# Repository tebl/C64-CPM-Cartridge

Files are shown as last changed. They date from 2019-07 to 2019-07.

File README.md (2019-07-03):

# C64 CP/M Cartridge

**UNTESTED**

Always wanted one of these for the original system, but they're hard to get so I've tried to recreate the cartridge itself for others to enjoy as well. For beginners and those with short memory, CP/M was professional choice of operating system for home computer markets - so if you wanted tax software, word processing and similar exciting tools this was the one you wanted for christmas. The system ran mainly on Z80-based systems while the Commodore 64 had a 6510 in it, so the cartridge was created in order to allow you to use the Z80 processor instead. Note that this is not a secondary processor, the Z80 shares all the main busses with the 6510 so only one of them can be active at a time.

There was no official schematic released for the module, none that I've seen anyway. Ruud Baltissen has taken upon himself the task of documenting the details of the module with a schematic, see his page at http://www.baltissen.org/newhtm/c64_cpm.htm for a lot more information on how the module works. My schematic has been transcribed from the one he made, then a PCB layout was done. Edge connector footprint was borrowed from the [Open16KCartridge](https://github.com/SukkoPera/OpenC64Cart16K) made by SukkoPera.

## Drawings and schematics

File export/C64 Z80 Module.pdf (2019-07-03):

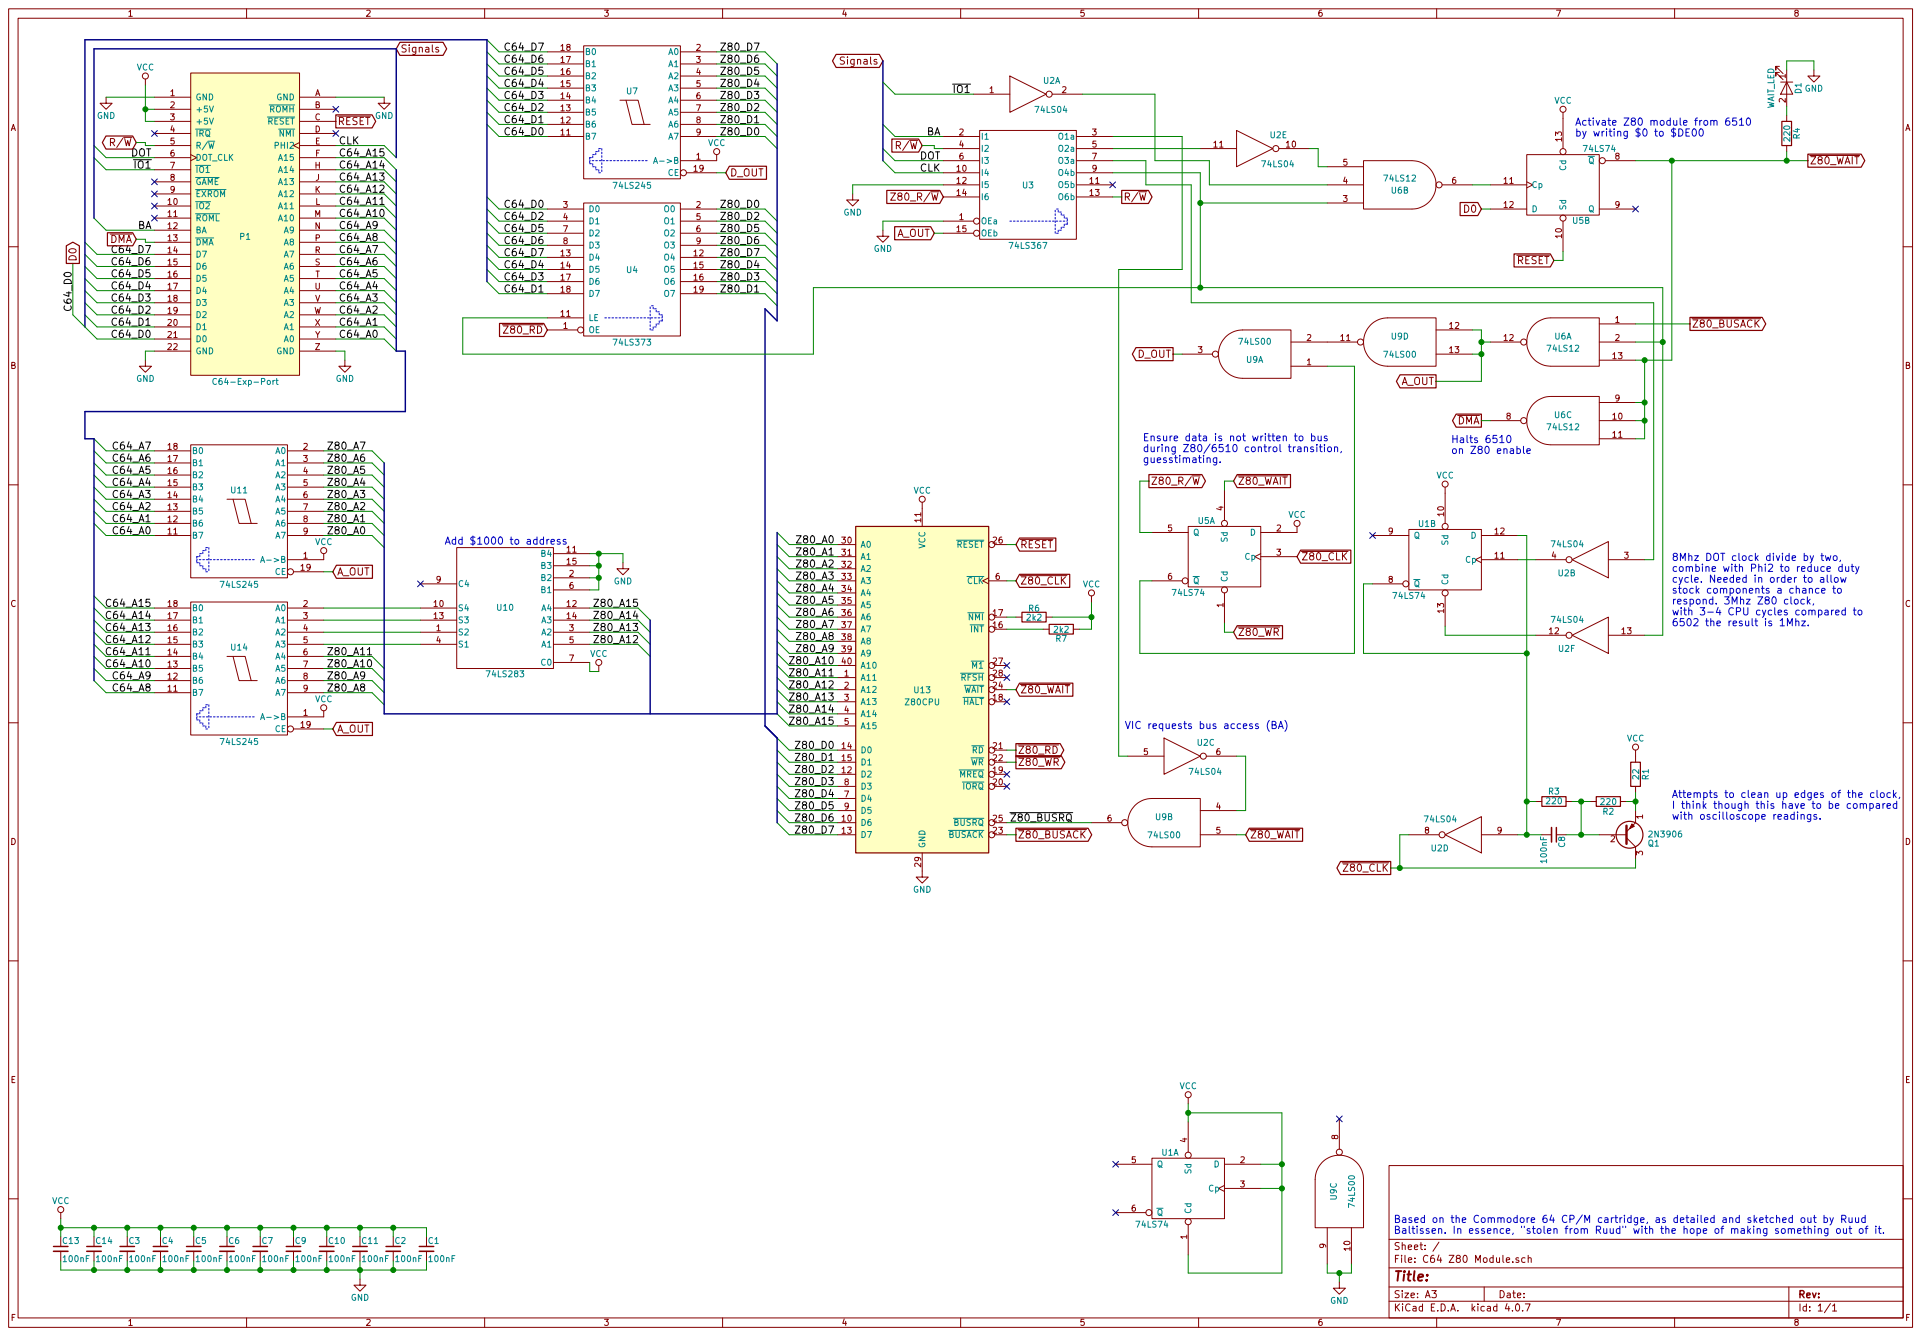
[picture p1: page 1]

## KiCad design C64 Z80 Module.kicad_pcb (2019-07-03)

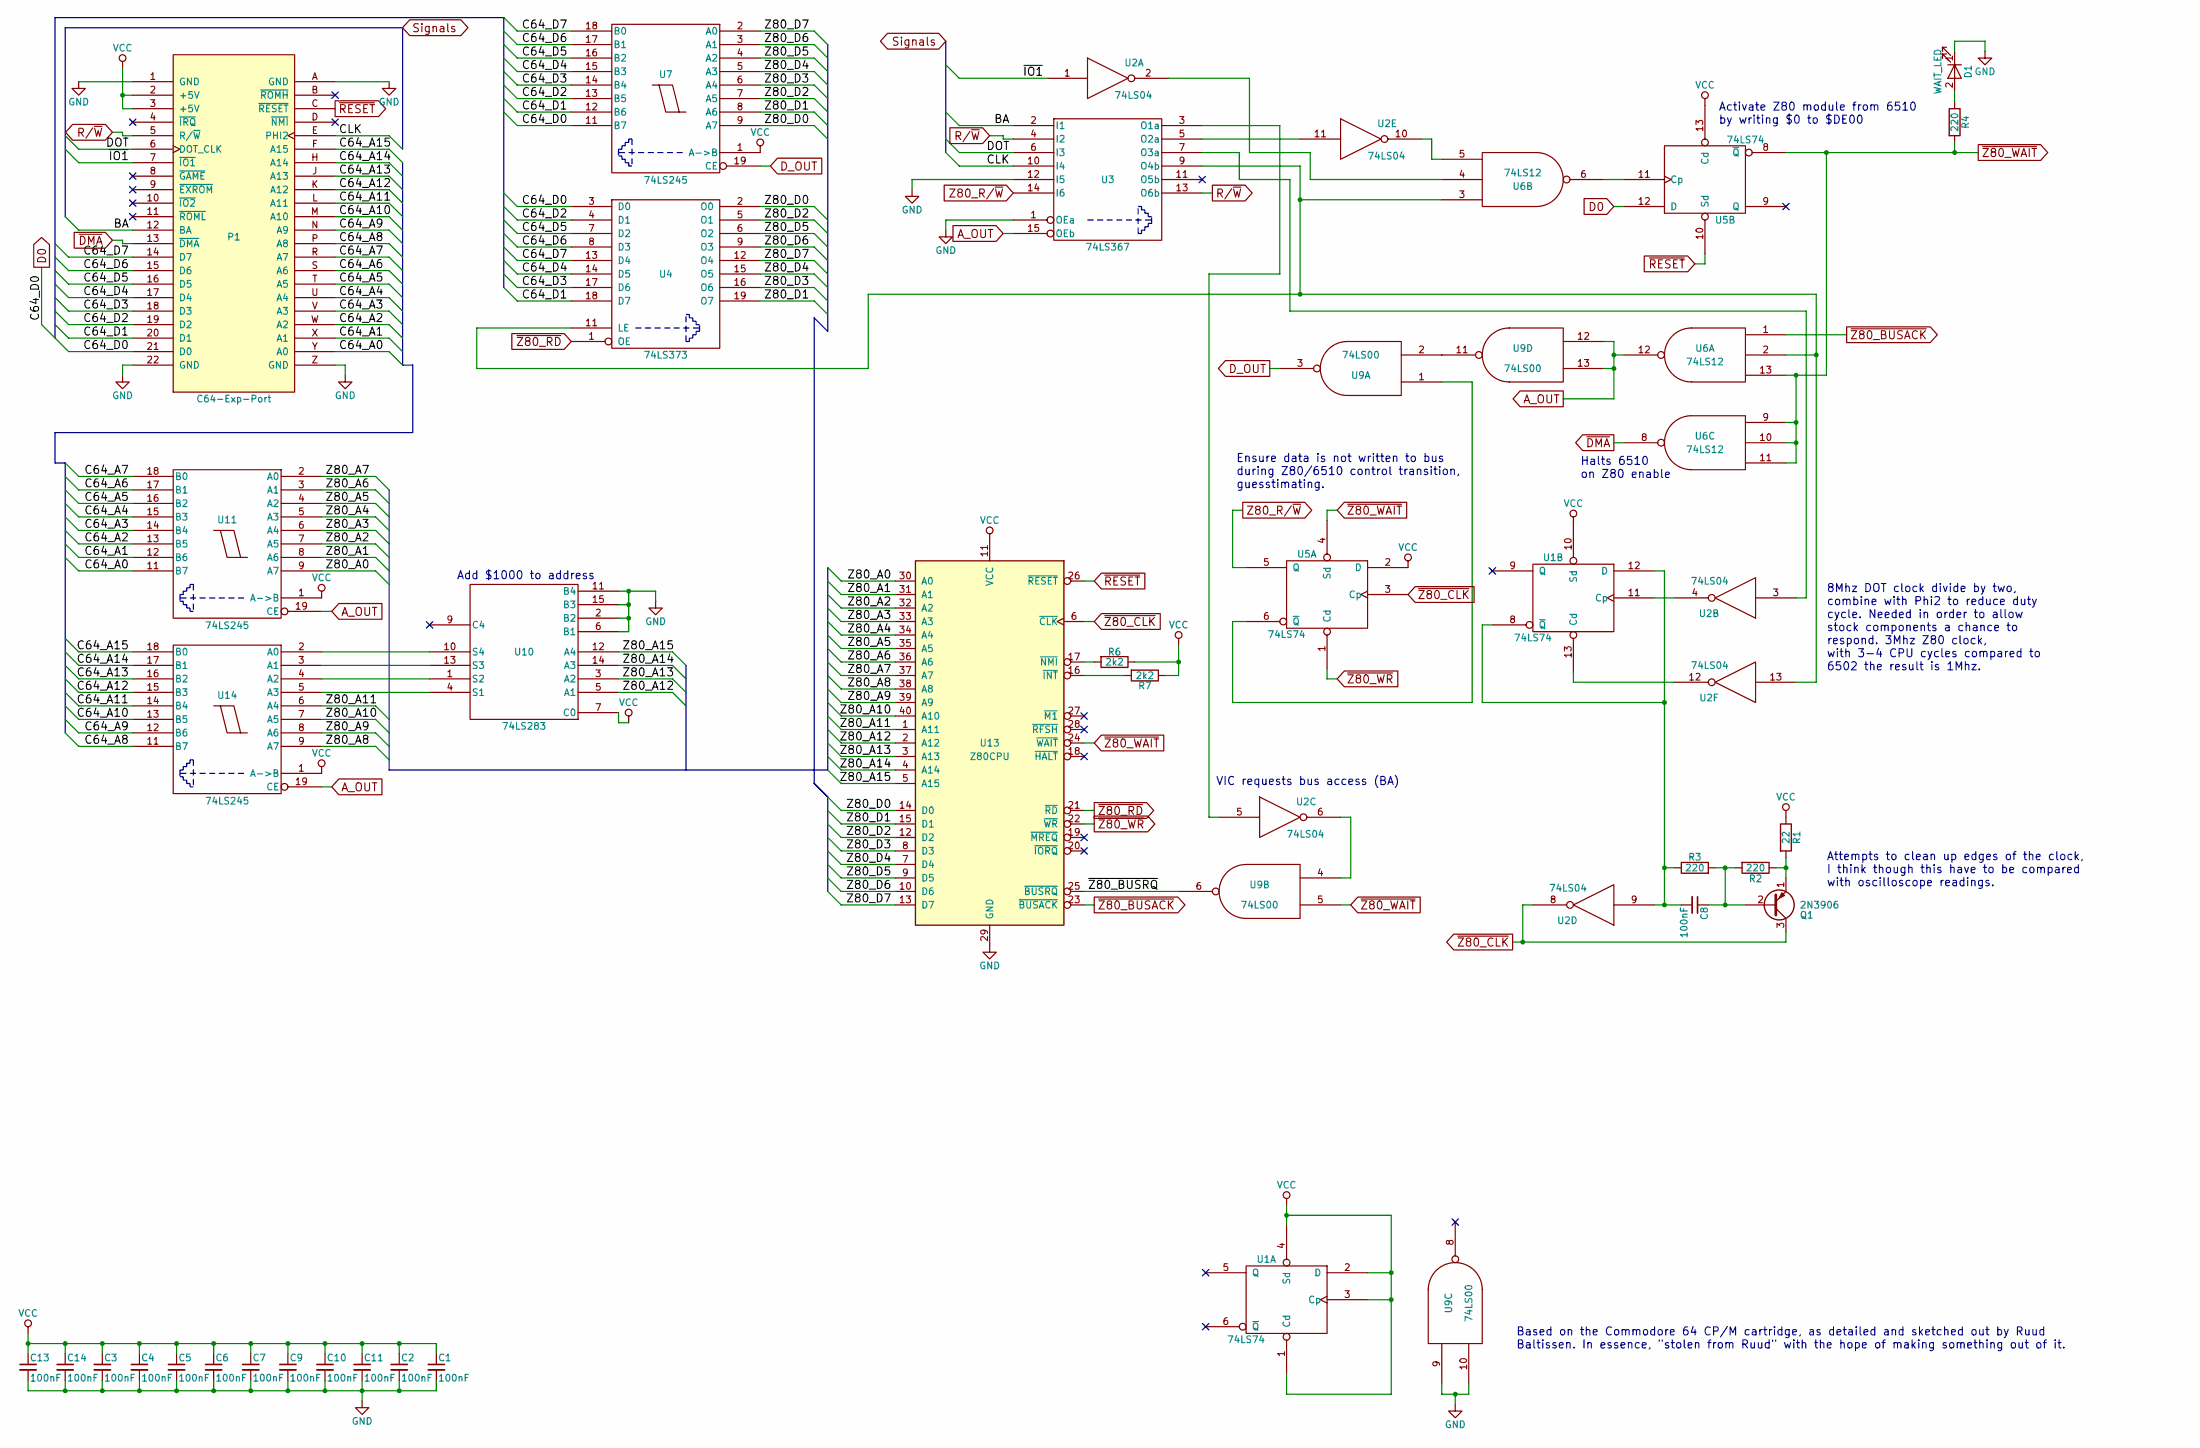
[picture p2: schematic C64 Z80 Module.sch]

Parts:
C1, C2, C3, C4, C5, C6, C7, C8, C9, C10, C11, C13, C14: 100nF; C_Disc_D4.7mm_W2.5mm_P5.00mm
D1: WAIT_LED; LED_D5.0mm
P1: C64-Exp-Port; C64-Cart
Q1: 2N3906; TO-92_Inline_Wide
R1: 22; R_Axial_DIN0207_L6.3mm_D2.5mm_P10.16mm_Horizontal
R2, R3, R4: 220; R_Axial_DIN0207_L6.3mm_D2.5mm_P10.16mm_Horizontal
R6, R7: 2k2; R_Axial_DIN0207_L6.3mm_D2.5mm_P10.16mm_Horizontal
U1, U5: 74LS74; DIP-14_W7.62mm_Socket
U2: 74LS04; DIP-14_W7.62mm_Socket
U3: 74LS367; DIP-16_W7.62mm_Socket
U4: 74LS373; DIP-20_W7.62mm_Socket
U6: 74LS12; DIP-14_W7.62mm_Socket
U7, U11, U14: 74LS245; DIP-20_W7.62mm_Socket
U9: 74LS00; DIP-14_W7.62mm_Socket
U10: 74LS283; DIP-16_W7.62mm_Socket
U13: Z80CPU; DIP-40_W15.24mm_Socket

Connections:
/BA: P1.12 (BA), U3.2 (I1)
/C64_A0: P1.Y (A0), U11.11 (B7)
/C64_A1: P1.X (A1), U11.12 (B6)
/C64_A2: P1.W (A2), U11.13 (B5)
/C64_A3: P1.V (A3), U11.14 (B4)
/C64_A4: P1.U (A4), U11.15 (B3)
/C64_A5: P1.T (A5), U11.16 (B2)
/C64_A6: P1.S (A6), U11.17 (B1)
/C64_A7: P1.R (A7), U11.18 (B0)
/C64_A8: P1.P (A8), U14.11 (B7)
/C64_A9: P1.N (A9), U14.12 (B6)
/C64_A10: P1.M (A10), U14.13 (B5)
/C64_A11: P1.L (A11), U14.14 (B4)
/C64_A12: P1.K (A12), U14.15 (B3)
/C64_A13: P1.J (A13), U14.16 (B2)
/C64_A14: P1.H (A14), U14.17 (B1)
/C64_A15: P1.F (A15), U14.18 (B0)
/C64_D1: P1.20 (D1), U4.18 (D7), U7.12 (B6)
/C64_D2: P1.19 (D2), U4.4 (D1), U7.13 (B5)
/C64_D3: P1.18 (D3), U4.17 (D6), U7.14 (B4)
/C64_D4: P1.17 (D4), U4.14 (D5), U7.15 (B3)
/C64_D5: P1.16 (D5), U4.7 (D2), U7.16 (B2)
/C64_D6: P1.15 (D6), U4.8 (D3), U7.17 (B1)
/C64_D7: P1.14 (D7), U4.13 (D4), U7.18 (B0)
/CLK: P1.E (PHI2), U3.10 (I4)
/DOT: P1.6 (DOT_CLK), U3.6 (I3)
/Z80_A0: U11.9 (A7), U13.30 (A0)
/Z80_A1: U11.8 (A6), U13.31 (A1)
/Z80_A2: U11.7 (A5), U13.32 (A2)
/Z80_A3: U11.6 (A4), U13.33 (A3)
/Z80_A4: U11.5 (A3), U13.34 (A4)
/Z80_A5: U11.4 (A2), U13.35 (A5)
/Z80_A6: U11.3 (A1), U13.36 (A6)
/Z80_A7: U11.2 (A0), U13.37 (A7)
/Z80_A8: U13.38 (A8), U14.9 (A7)
/Z80_A9: U13.39 (A9), U14.8 (A6)
/Z80_A10: U13.40 (A10), U14.7 (A5)
/Z80_A11: U13.1 (A11), U14.6 (A4)
/Z80_A12: U10.5 (A1), U13.2 (A12)
/Z80_A13: U10.3 (A2), U13.3 (A13)
/Z80_A14: U10.14 (A3), U13.4 (A14)
/Z80_A15: U10.12 (A4), U13.5 (A15)
/Z80_D0: U4.2 (O0), U7.9 (A7), U13.14 (D0)
/Z80_D1: U4.19 (O7), U7.8 (A6), U13.15 (D1)
/Z80_D2: U4.5 (O1), U7.7 (A5), U13.12 (D2)
/Z80_D3: U4.16 (O6), U7.6 (A4), U13.8 (D3)
/Z80_D4: U4.15 (O5), U7.5 (A3), U13.7 (D4)
/Z80_D5: U4.6 (O2), U7.4 (A2), U13.9 (D5)
/Z80_D6: U4.9 (O3), U7.3 (A1), U13.10 (D6)
/Z80_D7: U4.12 (O4), U7.2 (A0), U13.13 (D7)
/~IO1: P1.7 (~IO1), U2.1
/~Z80_BUSRQ: U9.6, U13.25 (~BUSRQ~)
A_OUT: U3.15 (OEb), U6.12, U9.12, U9.13, U11.19 (CE), U14.19 (CE)
D0: P1.21 (D0), U4.3 (D0), U5.12 (D), U7.11 (B7)
D_OUT: U7.19 (CE), U9.3
GND: C1.2, C2.2, C3.2, C4.2, C5.2, C6.2, C7.2, C9.2, C10.2, C11.2, C13.2, C14.2, D1.1 (K), P1.1 (GND), P1.22 (GND), P1.A (GND), P1.Z (GND), U1.7 (GND), U2.7 (GND), U3.1 (OEa), U3.8 (GND), U3.12 (I5), U4.10 (GND), U5.7 (GND), U6.7 (GND), U7.10 (GND), U9.7 (GND), U9.9, U9.10, U10.2 (B2), U10.6 (B1), U10.8 (GND), U10.11 (B4), U10.15 (B3), U11.10 (GND), U13.29 (GND), U14.10 (GND)
unnamed: C8.1, Q1.2 (B), R2.2, R3.2
unnamed: C8.2, R3.1, U1.8 (~Q), U1.12 (D), U2.9
unnamed: D1.2 (A), R4.1
unnamed: Q1.1 (E), R1.2, R2.1
unnamed: R6.2, U13.17 (~NMI~)
unnamed: R7.2, U13.16 (~INT~)
unnamed: U1.11 (Cp), U2.4
unnamed: U1.13 (Cd), U2.12
unnamed: U2.2, U6.4
unnamed: U2.3, U3.7 (O3a)
unnamed: U2.5, U3.3 (O1a)
unnamed: U2.6, U9.4
unnamed: U2.10, U6.5
unnamed: U2.11, U3.5 (O2a)
unnamed: U2.13, U3.9 (O4b), U4.11 (LE), U6.2, U6.3
unnamed: U5.6 (~Q), U9.1
unnamed: U5.11 (Cp), U6.6
unnamed: U9.2, U9.11
unnamed: U10.1 (S2), U14.4 (A2)
unnamed: U10.4 (S1), U14.5 (A3)
unnamed: U10.10 (S4), U14.2 (A0)
unnamed: U10.13 (S3), U14.3 (A1)
R/~W: P1.5 (R/~W), U3.4 (I2), U3.13 (O6b)
VCC: C1.1, C2.1, C3.1, C4.1, C5.1, C6.1, C7.1, C9.1, C10.1, C11.1, C13.1, C14.1, P1.2 (+5V), P1.3 (+5V), R1.1, R6.1, R7.1, U1.1 (Cd), U1.2 (D), U1.3 (Cp), U1.4 (Sd), U1.10 (Sd), U1.14 (VCC), U2.14 (VCC), U3.16 (VCC), U4.20 (VCC), U5.2 (D), U5.13 (Cd), U5.14 (VCC), U6.14 (VCC), U7.1 (A->B), U7.20 (VCC), U9.14 (VCC), U10.7 (C0), U10.16 (VCC), U11.1 (A->B), U11.20 (VCC), U13.11 (VCC), U14.1 (A->B), U14.20 (VCC)
Z80_R/~W: U3.14 (I6), U5.5 (Q)
~DMA: P1.13 (~DMA), U6.8
~RESET: P1.C (~RESET), U5.10 (Sd), U13.26 (~RESET~)
~Z80_BUSACK: U6.1, U13.23 (~BUSACK~)
~Z80_CLK: Q1.3 (C), U2.8, U5.3 (Cp), U13.6 (~CLK~)
~Z80_RD: U4.1 (OE), U13.21 (~RD~)
~Z80_WAIT: R4.2, U5.4 (Sd), U5.8 (~Q), U6.9, U6.10, U6.11, U6.13, U9.5, U13.24 (~WAIT~)
~Z80_WR: U5.1 (Cd), U13.22 (~WR~)

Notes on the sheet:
Add $1000 to address
Activate Z80 module from 6510 by writing $0 to $DE00
VIC requests bus access (BA)
Halts 6510 on Z80 enable
8Mhz DOT clock divide by two, combine with Phi2 to reduce duty cycle. Needed in order to allow stock components a chance to respond. 3Mhz Z80 clock, with 3-4 CPU cycles compared to 6502 the result is 1Mhz.
Based on the Commodore 64 CP/M cartridge, as detailed and sketched out by Ruud Baltissen. In essence, "stolen from Ruud" with the hope of making something out of it.
Attempts to clean up edges of the clock, I think though this have to be compared with oscilloscope readings.
Ensure data is not written to bus during Z80/6510 control transition, guesstimating.

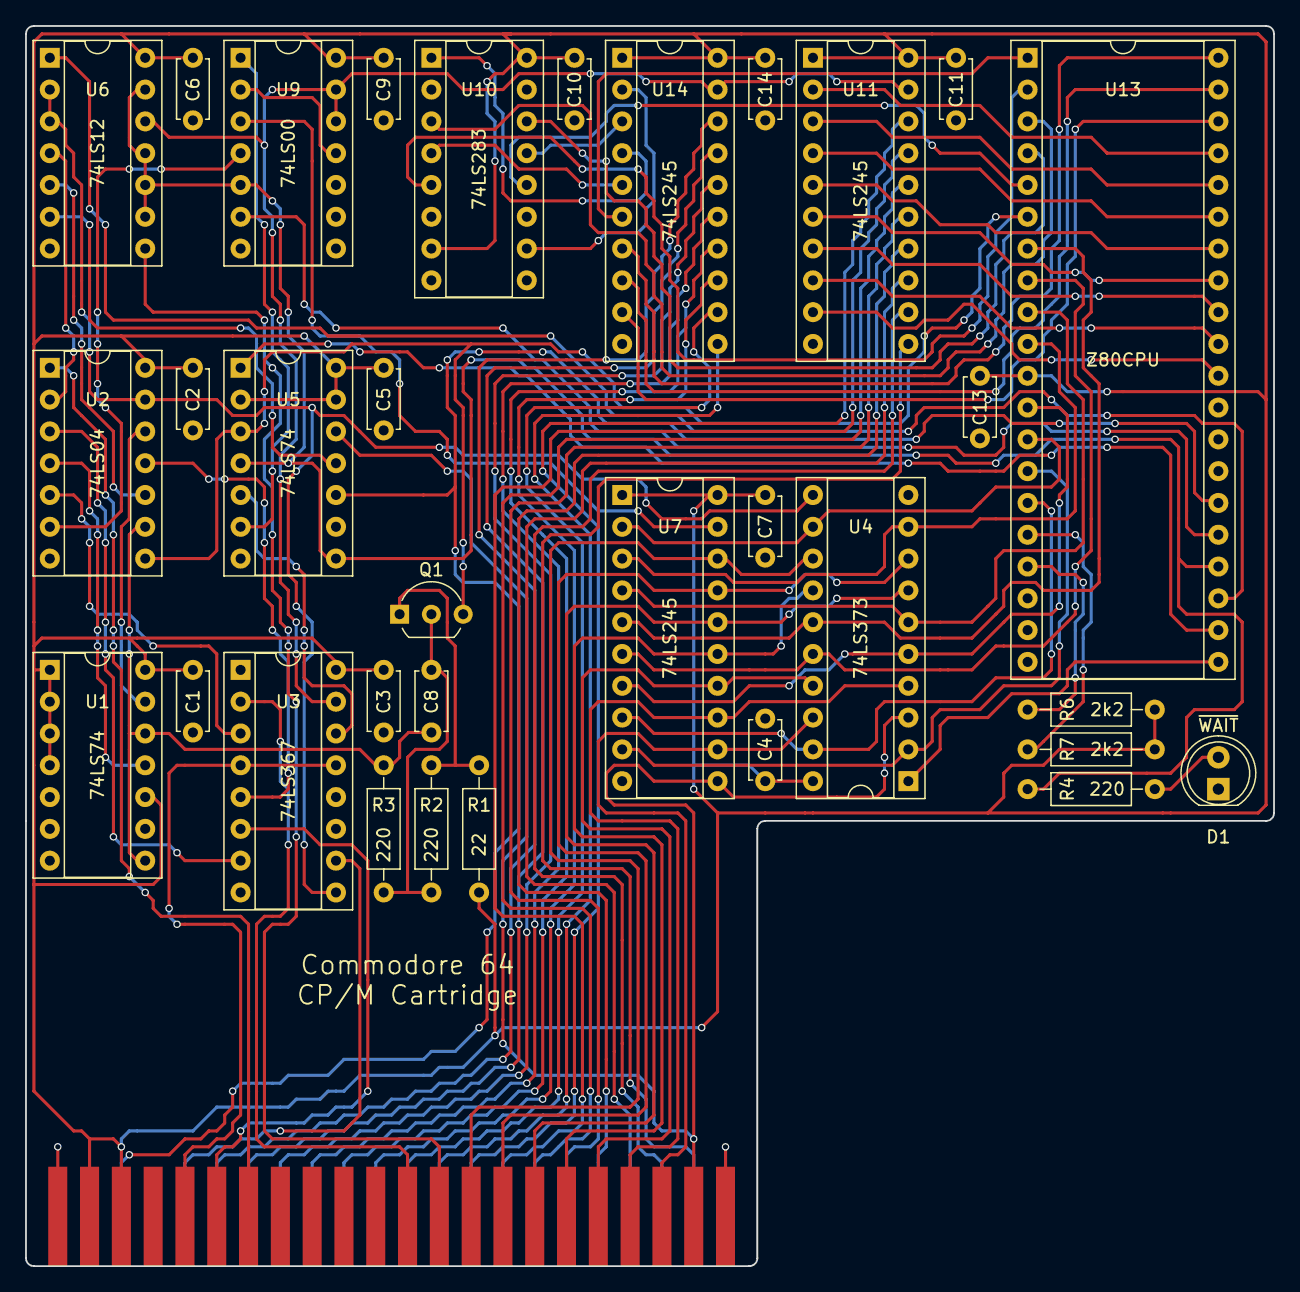
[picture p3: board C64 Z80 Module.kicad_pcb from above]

Board: 2 copper layers, 99.7 x 99.1 mm, 34 parts (0 on the bottom side), 88 nets.

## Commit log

2019-07-01 Schematic transcribed
    [C64 Z80 Module.kicad_pcb, C64 Z80 Module.sch]
2019-07-01 Fixed errors (by ignoring them)
    [C64 Z80 Module.sch]
2019-07-01 Added notes to schematic for easier read
    [C64 Z80 Module.sch]
2019-07-02 Assigned footprints
    [C64 Z80 Module.sch]
2019-07-03 Layout done
    [C64 Z80 Module.kicad_pcb, C64 Z80 Module.sch]
2019-07-03 Gerber export
    [C64 Z80 Module-B.Cu.gbl, C64 Z80 Module-B.Mask.gbs, C64 Z80 Module-B.Paste.gbp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]
